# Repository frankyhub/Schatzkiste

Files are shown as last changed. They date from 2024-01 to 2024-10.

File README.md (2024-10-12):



<div align="center">

|[:skull:ISSUE](https://github.com/frankyhub/Schatzkiste/issues?q=is%3Aissue)|[:speech_balloon: Forum /Discussion](https://github.com/frankyhub/Schatzkiste/discussions)|[:grey_question:WiKi](https://github.com/frankyhub/Schatzkiste/wiki)||
|--|--|--|--|
| | | | |
||<a href="https://github.com/frankyhub/Schatzkiste/issues">|<a href="https://github.com/frankyhub/Schatzkiste/discussions">|<a href="https://github.com/frankyhub/Schatzkiste/releases">|
|| <a href="https://github.com/frankyhub/Schatzkiste/pulse" alt="Activity">| <a href="https://github.com/frankyhub/Schatzkiste/graphs/traffic">  |<a href="https://github.com/frankyhub?tab=stars"> |
</div>

# Schatzkiste

## Story

Mit diesem Projekt wird eine Schatzkiste gebaut, die sich mit dem Betätigen von vier Tasten in der 
richtigen Reihenfolge öffnen lässt. Wird eine Taste betätigt, leuchtet die darüber liegende LED. 
Ist der Tasten-Code richtig eingegeben, gehen die vier weißen LEDs über den Tasten aus, eine grüne 
LED leuchtet und die beiden Servo-Motoren öffnen den Verschluss. Ist die Schatzkiste geöffnet, kann mit jeder 
beliebigen Taste die Schatzkiste wieder verschlossen werden. Ist der Code falsch eingegeben, erlöschen 
die vier LEDS und die Schatzkiste bleibt verschlossen.
Im inneren der Schatzkiste ist ein Reed-Kontakt versteckt. Nur der Eigentümer der Schatzkiste weiß, 
wo sich der Reed-Kontakt befindet. Wird an diesen Reed-Kontakt ein Magnet gehalten, blinken die vier 
Taster-LEDs und der Code kann neu programmiert werden. Nach erfolgreicher Programmierung blinken die 
vier Taster-LEDs erneut. Der Code wird in das EEPROM des NANO geladen, so dass auch bei Spannungsausfall 
der Code erhalten bleibt.

Die Schatzkiste

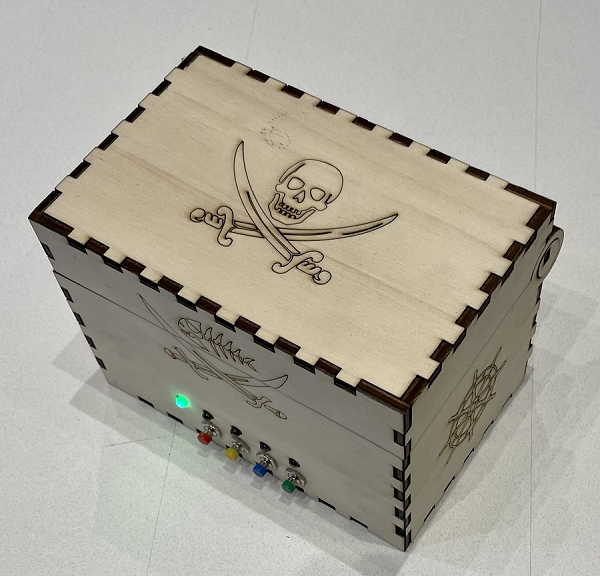
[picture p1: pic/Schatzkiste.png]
Schatzkiste


---

## Hardware
Die Stückliste für die Schatzkiste:

+ 1 x NANO
+ 1 x NANO-Shield
+ 2 x Buchsenleisten
+ 2 x Stiftleisten
+ 2 x Servo Motore SG90
+ 2 x 90° Verschluss Winkel
+ 1 x Reed-Kontakt mit Magnet
+ 4 x Taster
+ 4 x LEDs weiß
+ 1 x LED grün
+ 5 x 1kOhm Widerstand
+ 1 x 9V Batterie
+ 1 x 9V Batterie-Clip
+ 1 x Gelaserte Schatzkiste (4mm Sperrholz 600x300)

---

## Aufbau und Montage
Der Aufbau und die Montage der Schatzkiste ist in mehrere Schritte unterteilt.

## Schritt 1: Das Gehäuse
+ Erstelle auf Boxes.PY  eine "Kiste mit eingebundenen Schanier" mit den Abmessungen x=160, y=100 und h=80, Deckelhöhe 28.
+ Füge in die erstellte SVG-Grafik die Löcher für die LEDs und Taster ein
+ Füge in die erstellte SVG-Grafik deine Grafik für die Verziehrung der Schatzkiste ein
+ Schneide das Gehäuse mit dem Lasercutter aus
+ Klebe die Servo-Motoren in den Gehäusedeckel
+ Klebe die Winkel an die Frontplatte
+ Klebe den Reed-Kontakt in das Gehäuse
+ Montiere die LEDs und die Taster an die Gehäuse-Front
+ Verklebe die Gehäuseteile. Die untere Rückwand wird nicht verklebt

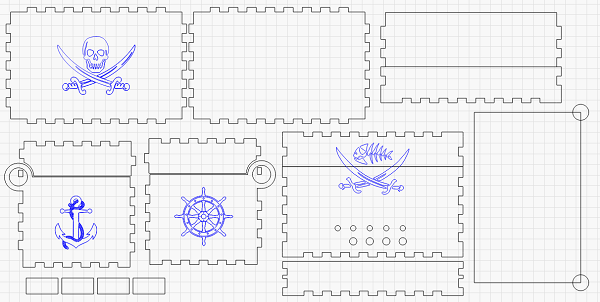
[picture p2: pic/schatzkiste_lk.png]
Schatzkiste


---

## Schritt 2: 3D-Druck
+ Zeichne und drucke 4 Platinen Füße für den NANO, D=5mm x 5mm
+ Klebe die Füße auf die Unterseite des NANO-Shields

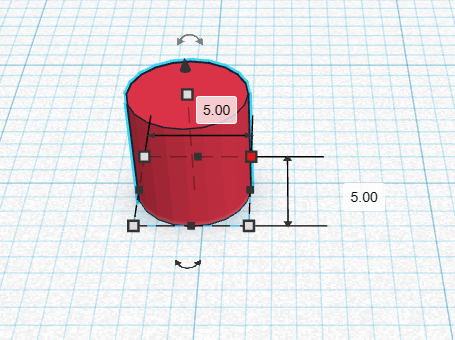
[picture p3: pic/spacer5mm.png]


---

## Schritt 3: Verdrahtung und Lötarbeiten
+ Bestücke das NANO-Shield mit den Buchsenleisten und den beiden Stiftleisten für die Servo-Motore
+ Biege an einem Ende der Widerstände und am +Pol der LEDs eine Öse

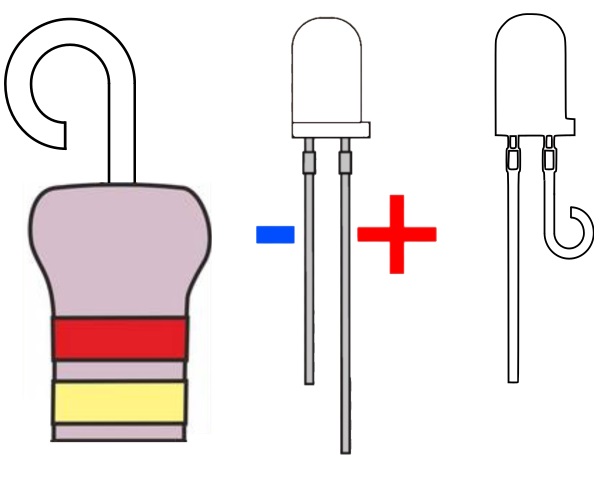
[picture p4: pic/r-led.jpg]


Führe Anschlussdrähte für die Widerstände und der LEDs durch die Öse und Löte sie an

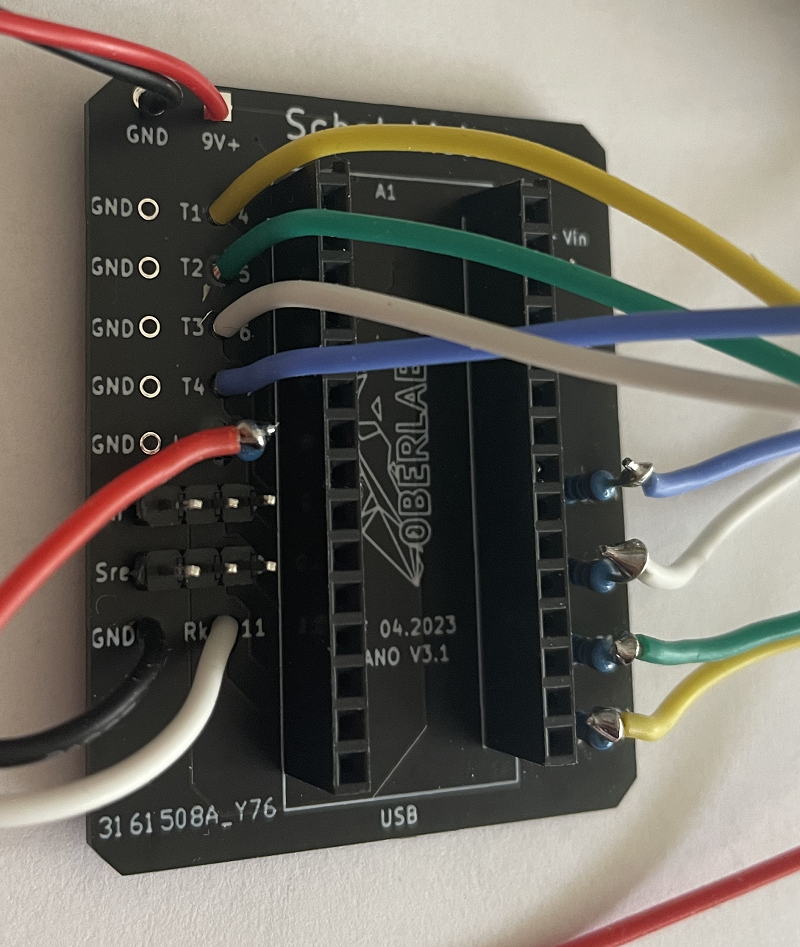
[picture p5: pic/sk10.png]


Schatzkiste

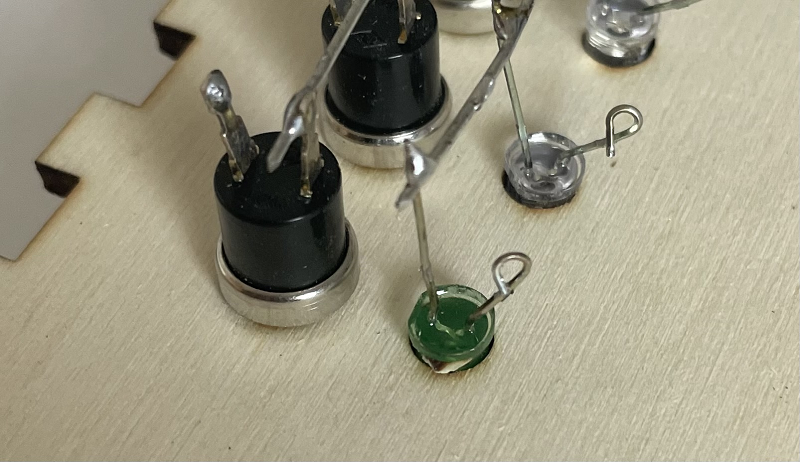
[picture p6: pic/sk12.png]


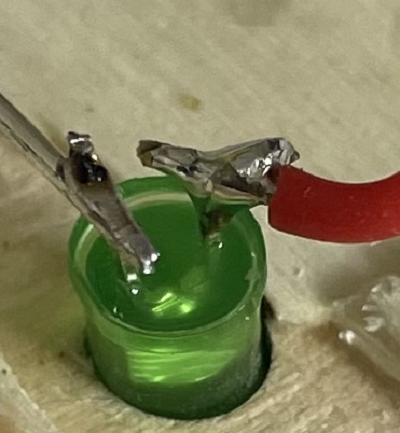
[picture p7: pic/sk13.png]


Verdrahte das Shield, die LEDs, Taster und den Reed-Kontakt nach den Verdrahtungsplan

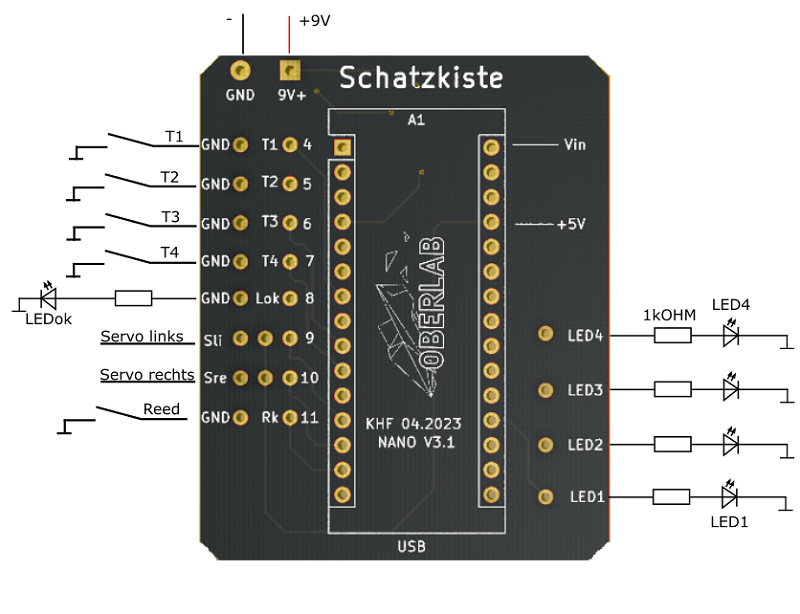
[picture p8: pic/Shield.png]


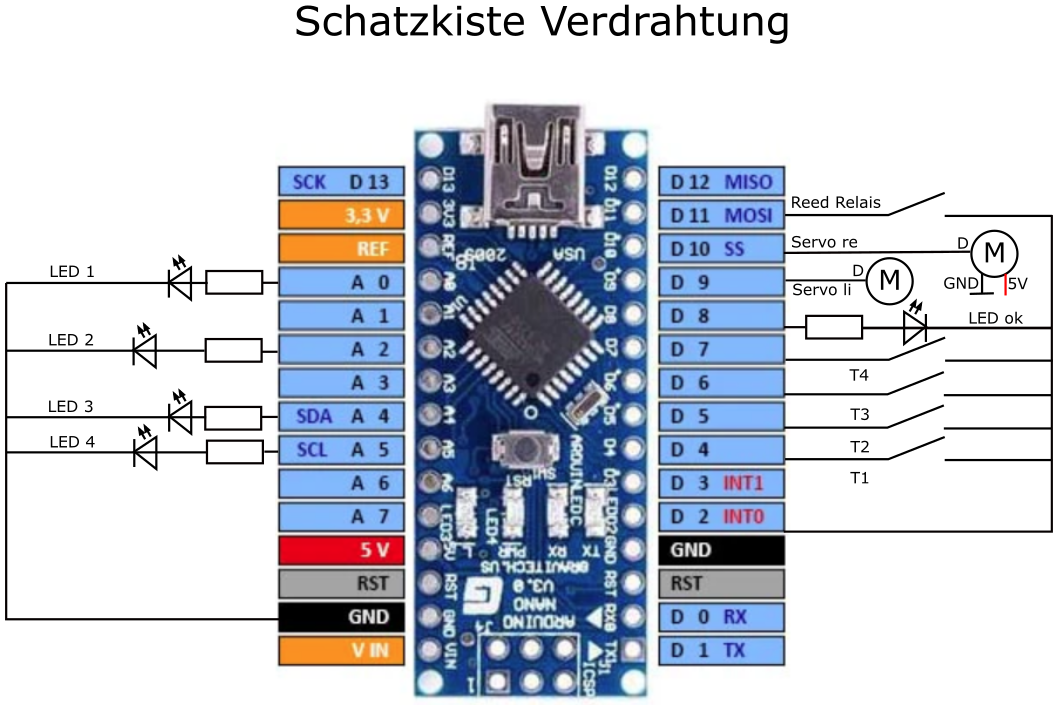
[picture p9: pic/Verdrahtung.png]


---

## Schritt 4: Inbetriebnahme
+ Kontrolliere alle Verbindungen
+ Lade das Servo-Test Programm in den NANO
+ Versorge die Schatzkiste mit Spannung
+ Teste den Verschluss-Mechanismus mit den Servo-Motoren
+ Wenn der Verschluss ok ist, lade das Haupt-Programm in den NANO
+ Das Programm befindet sich auf deinen Laptop unter Nextcloud/Schatzkiste
+ Aktiviere mit einen Magneten über den Reed-Kontakt die Programmierung des Codes
+ Gibt über die Taster deinen Code ein
+ Teste deinen Code
+ Ist der Code richtig, öffen die Servo-Motor die Verschluss-Einrichtung

---

<div style="position:absolute; left:2cm; ">   
<ol class="breadcrumb" style="border-top: 2px solid black;border-bottom:2px solid black; height: 45px; width: 900px;"> <p align="center"><a href="#oben">nach oben</a></p></ol>
</div>

---

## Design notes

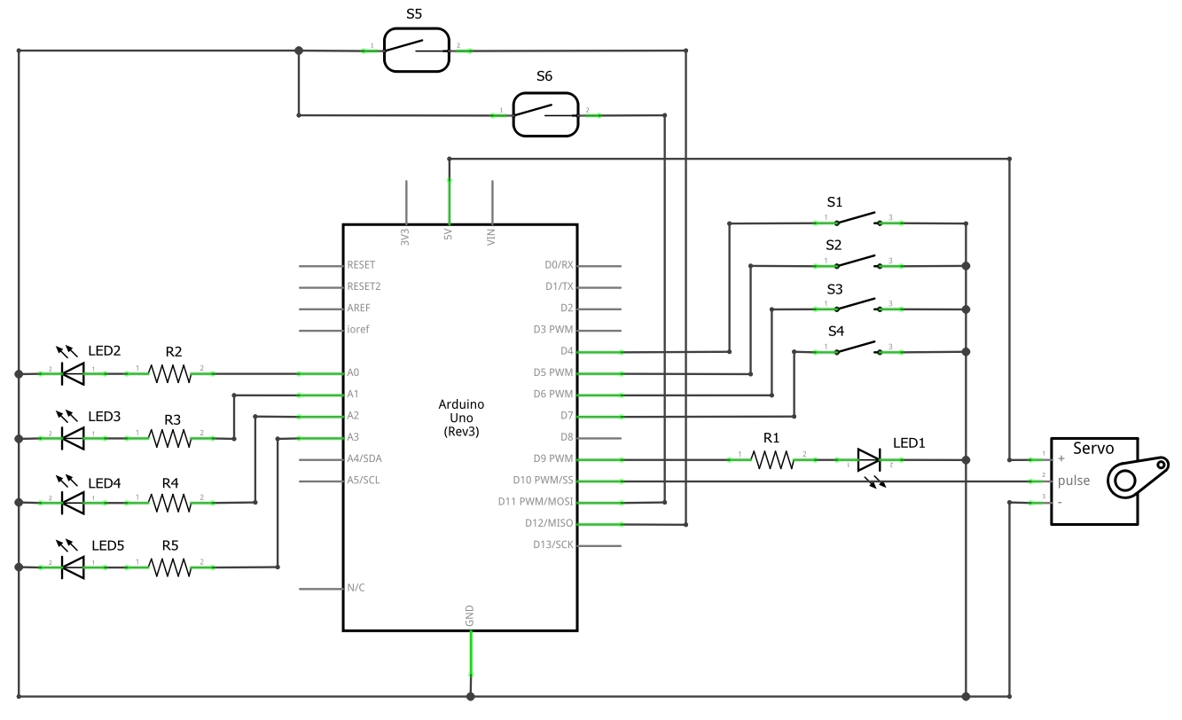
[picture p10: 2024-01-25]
pic/Schaltplan.png

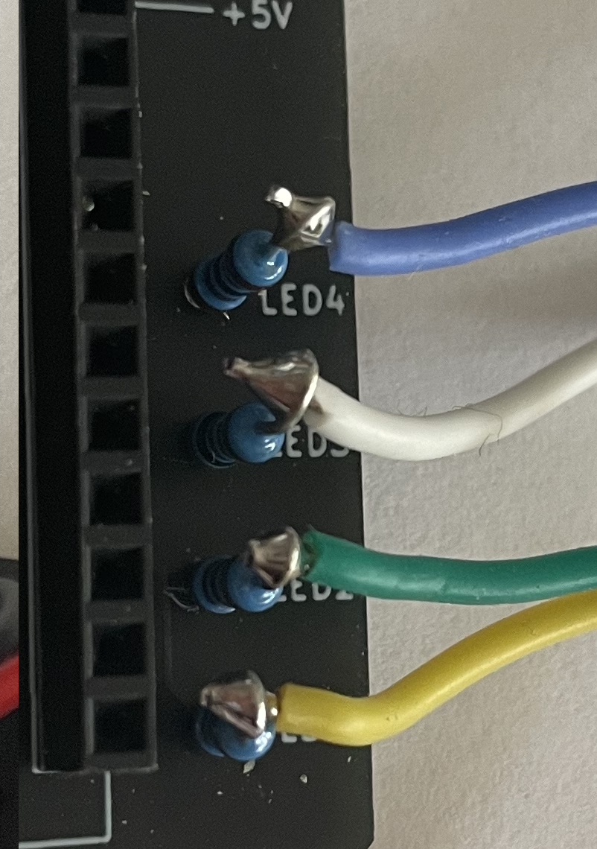
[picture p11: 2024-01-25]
pic/sk11.png

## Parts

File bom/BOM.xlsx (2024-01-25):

 | BOM Schatzkiste
10 | 1 x NANO | 60.00 € | 6.00 € | Amazon (https://www.amazon.de/dp/B078S8BJ8T/ref=twister_B07ZP9RH6Q?_encoding=UTF8&psc=1)
10 | 1 x NANO-Shield | 30.00 € | 3.00 €
10 | 1x Stift/Buchsenleiste | 10.00 € | 1.00 € | Amazon (https://www.amazon.de/gp/product/B07CC4V9ZY/ref=ppx_yo_dt_b_asin_title_o09_s00?ie=UTF8&psc=1)
20 | 2 x Servo Motor SG90 | 40.00 € | 4.00 € | Amazon (https://www.amazon.de/XTVTX-Flugzeug-Hubschrauber-Helicopter-Airplane/dp/B0BG2RDC21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)
10 | 1 x Reed-Kontakt mit Magnet | 10.00 € | 1.00 € | Amazon (https://www.amazon.de/Gebildet-Reedschalter-Magnetischer-Induktionsschalter-Mehrzweckmagneten/dp/B07Z4RR4QV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)
40 | 4 x Taster | 20.00 € | 2.00 € | Amazon (https://www.amazon.de/RUNCCI-YUN-Momentane-Druckschalter-Armaturenbrett-Montageloch%EF%BC%89/dp/B087V5VKKY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)
40 | 4 x LEDs weiß | 9.00 € | 0.90 € | Amazon (https://www.amazon.de/Lumetheus-Farbe-14-000-St%C3%BCck-Leuchtdiode/dp/B083HMLCC7)
10 | 1 x LED grün | 7.00 € | 0.70 € | Amazon (https://www.amazon.de/Lumetheus-Farbe-14-000-St%C3%BCck-Leuchtdiode/dp/B083HMLCC7)
50 | 5 x 1kOhm | 6.60 € | 0.66 € | Amazon (https://www.amazon.de/Widerstand-Verwendbar-Resistor-Suitable-A2417/dp/B07KX37J53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)
10 | 1 x 9V Batterie | 11.00 € | 1.10 € | Amazon (https://www.amazon.de/Varta-Industrial-Batterie-Alkaline-Batterien-blau/dp/B00149O6ZQ)
10 | 1 x 9V Batterie-Clip | 7.00 € | 0.70 € | Amazon (https://www.amazon.de/mmtrade-Batterieclip-9-Volt-Batterie-Anschlusskabel/dp/B09N1NQFYZ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)
20 | 2 x 90° Winkel | 6.00 € | 0.60 € | Amazon (https://www.amazon.de/gp/product/B09PFMV4L9/ref=ppx_yo_dt_b_asin_title_o00_s00?ie=UTF8&psc=1)
10 | 1 x Gelaserte Schatzkiste (4mm Sperrholz 600x300) | 40.00 € | 4.00 €
 |  | 256.60 € | 25.66 €

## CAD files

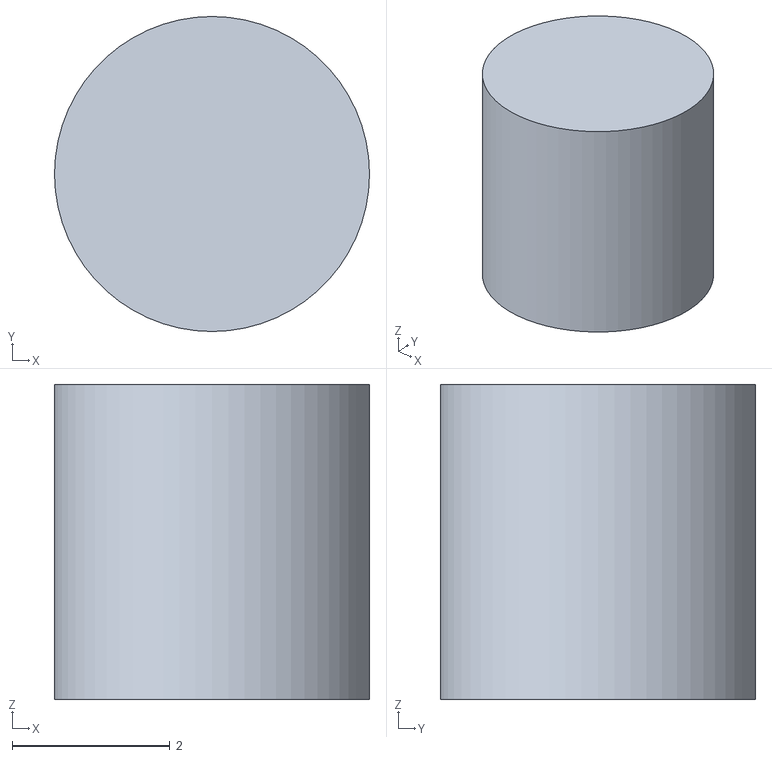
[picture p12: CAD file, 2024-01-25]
3D/Pin 4x4.stl
4.00 x 4.00 x 4.00

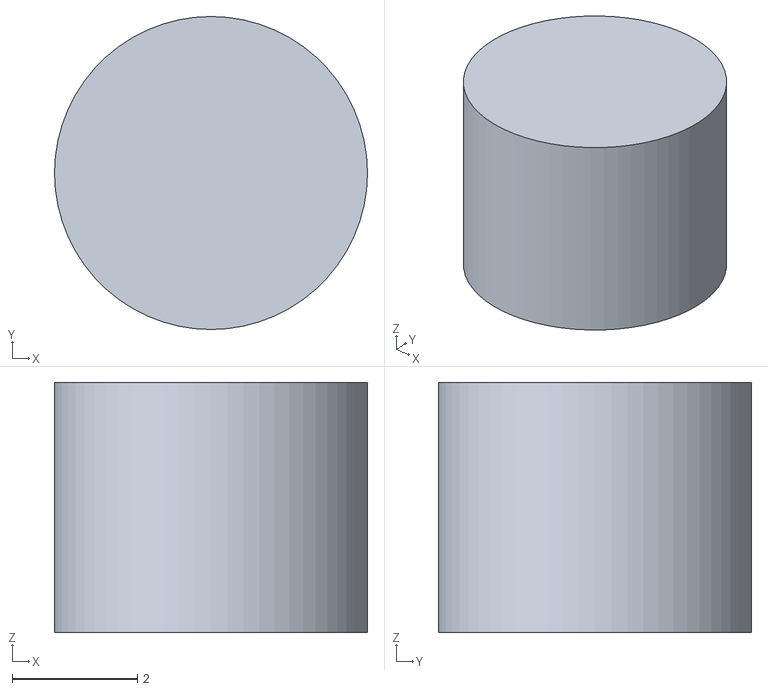
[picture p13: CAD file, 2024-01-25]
3D/Pin 4x5.stl
5.00 x 5.00 x 4.00

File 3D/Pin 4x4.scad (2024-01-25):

$fn=60;
cylinder(h=4,d=4);

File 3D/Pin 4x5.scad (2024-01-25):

$fn=60;
cylinder(h=4,d=5);

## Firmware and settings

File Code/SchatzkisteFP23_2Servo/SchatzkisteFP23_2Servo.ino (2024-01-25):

/************************************************************************************************* 
                                      PROGRAMMINFO
************************************************************************************************** 
Funktion: Schatzkiste

Mit diesem Projekt wird eine Schatzkiste gebaut, die sich mit dem Betätigen von vier Tasten in der 
richtigen Reihenfolge öffnen lässt. Wird eine Taste betätigt, leuchtet die darüber liegende LED. 
Ist der Tasten-Code richtig eingegeben, gehen die vier weißen LEDs über den Tasten aus, eine grüne 
LED leuchtet und der Servo-Motor öffnet den Verschluss. Ist die Schatzkiste geöffnet, kann mit jeder 
beliebigen Taste die Schatzkiste wieder verschlossen werden. Ist der Code falsch eingegeben, erlöschen 
die vier LEDS und die Schatzkiste bleibt verschlossen.
Im inneren der Schatzkiste ist ein Reed-Kontakt versteckt. Nur der Eigentümer der Schatzkiste weiß, 
wo sich der Reed-Kontakt befindet. Wird an diesen Reed-Kontakt ein Magnet gehalten, blinken die vier 
Taster-LEDs und der Code kann neu programmiert werden. Nach erfolgreicher Programmierung blinken die 
vier Taster-LEDs erneut. Der Code wird in das EEPROM des NANO geladen, so dass auch bei Spannungsausfall 
der Code erhalten bleibt.
**************************************************************************************************
*Die Hardware für die Schatzkiste
1 x NANO
2 x Servo Motor SG90
1 x Reed-Kontakt mit Magnet
4 x Taster
4 x LEDs weiß
1 x LED grün
1 x 9V Batterie
1 x 9V Batterie-Clip
1 x Gelaserte Schatzkiste (4mm Sperrholz 600x300)
**************************************************************************************************
*Version: 30.01.2023
**************************************************************************************************
Board: NANO
**************************************************************************************************
C++ Arduino IDE V1.8.13
**************************************************************************************************
Einstellungen:
https://dl.espressif.com/dl/package_esp32_index.json
http://dan.drown.org/stm32duino/package_STM32duino_index.json
https://raw.githubusercontent.com/espressif/arduino-esp32/gh-pages/package_esp32_dev_index.json
**************************************************************************************************
Librarys
- Servo.h  V 1.1.6
- EEPROM.h V 1.1.0
**************************************************************************************************
 */
#define PIN_LED_1         A0  //LED 1 
#define PIN_LED_2         A2  //LED 2  
#define PIN_LED_3         A4  //LED 3
#define PIN_LED_4         A5  //LED 4
#define PIN_BUTTON_1      4   //S1
#define PIN_BUTTON_2      5   //S2
#define PIN_BUTTON_3      6   //S3
#define PIN_BUTTON_4      7   //S4
#define PIN_LED_SUCCESS   8   //LED Code OK
#define PIN_SERVO1        9   //Servo1 rechts
#define PIN_SERVO2        10  //Servo2 links
#define PIN_REED_1        11  //S5 Reed-Relais


#include <Servo.h>  
#include <EEPROM.h> 

bool isDoorOpen, openDoor, buttonPressed[4];
byte buttons[4] = {PIN_BUTTON_1, PIN_BUTTON_2, PIN_BUTTON_3, PIN_BUTTON_4};
byte leds[4] = {PIN_LED_1, PIN_LED_2, PIN_LED_3, PIN_LED_4}, doorCode[4];
Servo servoMotor1;
Servo servoMotor2;

void setup()
{
  Serial.begin(115200);
  Serial.print("Init...");
  pinMode(PIN_REED_1, INPUT_PULLUP);
//  pinMode(PIN_REED_2, INPUT_PULLUP);

  pinMode(PIN_LED_SUCCESS, OUTPUT);
  digitalWrite(PIN_LED_SUCCESS, LOW);

  for (byte i = 0; i < sizeof(leds); i++) {
    pinMode(leds[i], OUTPUT);
    pinMode(buttons[i], INPUT_PULLUP);
    buttonPressed[i] = false;
  }

  blinkLEDs();
  servoMotor1.attach(PIN_SERVO1);
  servoMotor1.write(0);
  servoMotor2.attach(PIN_SERVO2);
  servoMotor2.write(90);
  
  isDoorOpen = false;

  EEPROM.get(0, doorCode);
  Serial.println("ok");

  printDoorCode();
}

void loop()
{
  checkCode();
    if (digitalRead(PIN_REED_1) == LOW) {
// if (digitalRead(PIN_REED_1) == LOW && digitalRead(PIN_REED_2) == LOW) {
  Serial.print("Reste Code");
    resetCode();
  }
  checkDoor();
}

void checkCode()
{
  static byte foundOffset = 0, pressOffset = 0, currentState;
  openDoor = false;

  for (byte i = 0; i < sizeof(buttons); i++) {
    currentState = digitalRead(buttons[i]);
    if (!buttonPressed[i] && currentState == LOW) {
      digitalWrite(leds[i], HIGH);
      buttonPressed[i] = true;
      pressOffset++;
      if (doorCode[foundOffset] == i) {
        foundOffset++;
      }
    }
  }

  if (foundOffset >= 4) {
    openDoor = true;
    pressOffset = 0;
    foundOffset = 0;
    delay(200);
  } else {
    if (pressOffset >= 4) {
      pressOffset = 0;
      foundOffset = 0;
      for (byte i = 0; i < sizeof(buttons); i++) {
        delay(200);
        buttonPressed[i] = false;
        digitalWrite(leds[i], LOW);
      }
    }
  }
}

void checkDoor()
{
  if (!isDoorOpen) {
    if (openDoor) {
      digitalWrite(PIN_LED_SUCCESS, HIGH);
      for (byte i = 0; i < sizeof(leds); i++) {
        digitalWrite(leds[i], LOW);
      }
      delay(500);
      servoMotor1.write(90);
      servoMotor2.write(0);
      isDoorOpen = true;

      delay(1000);
      while (openDoor == true) {
        for (byte i = 0; i < sizeof(buttons); i++) {
          if (digitalRead(buttons[i]) == LOW) {
            openDoor = false;
            break;
          }
        }
      }
    }
  } else {
    if (!openDoor) {
      digitalWrite(PIN_LED_SUCCESS, LOW);
      for (byte i = 0; i < sizeof(leds); i++) {
        buttonPressed[i] = false;
        digitalWrite(leds[i], LOW);
      }
      servoMotor1.write(0);
      servoMotor2.write(90);
      isDoorOpen = false;
      delay(2000);
    }
  }
}

void resetCode()
{
  servoMotor1.write(90);
  servoMotor2.write(0);
  for (byte i = 0; i < sizeof(doorCode); i++) {
    doorCode[i] = 255;
  }
  blinkLEDs();
  openDoor = false;
  isDoorOpen = false;
  bool isExisting = false;
  byte offset = 0;
  do {
    for (byte i = 0; i < sizeof(buttons); i++) {
      isExisting = false;
      if (digitalRead(buttons[i]) == LOW && doorCode[offset] == 255) {
        for (byte j = 0; j < sizeof(doorCode); j++) {
          if (doorCode[j] == i) {
            isExisting = true;
          }
        }
        if (!isExisting) {
          digitalWrite(leds[i], HIGH);
          doorCode[offset] = i;
          offset++;
        }
      }
    }
  } while (offset < 4);

  printDoorCode();
  EEPROM.put(0, doorCode); // writing code to EEPROM
  servoMotor1.write(0);
  servoMotor2.write(90);
  blinkLEDs();
}

void blinkLEDs()
{
  for (byte j = 0; j < 9; j++) {
    for (byte i = 0; i < sizeof(leds); i++) {
      digitalWrite(leds[i], j % 2);
      delay(40);
    }
  }
}

void printDoorCode()
{
  Serial.println("Code:");
  for (byte i = 0; i < sizeof(doorCode); i++) {
    Serial.print(" ");
    Serial.print(doorCode[i]);
      Serial.println();
  }
}

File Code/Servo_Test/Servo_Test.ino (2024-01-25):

/*************************************************************************************************
                                      PROGRAMMINFO
**************************************************************************************************
  Funktion: Schatzkiste Servo Test
          Die Servos müssen sich zum öffnen der Schazkiste entgegengesetzt bewegen

  Servo links D9
  Servo rechte D10
  Taster  D7 betätigt/geschlossen => GND, 

**************************************************************************************************
  Version: 28.01.2023
**************************************************************************************************
  Board: NANO 1.6.21
**************************************************************************************************
  Libraries:
  https://github.com/espressif/arduino-esp32/tree/master/libraries
  C:\Users\User\Documents\Arduino
  D:\gittemp\Arduino II\A156_Wetterdaten_V3
**************************************************************************************************
  C++ Arduino IDE V1.8.19

**************************************************************************************************
  Einstellungen:
  https://dl.espressif.com/dl/package_esp32_index.json
  http://dan.drown.org/stm32duino/package_STM32duino_index.json
  http://arduino.esp8266.com/stable/package_esp8266com_index.json
**************************************************************************************************/
#include <Servo.h>

Servo myservo_li; //Servo links
Servo myservo_re; //Servo rechts

int pos = 0;
int button = 7;  //button = LOW -> Schatzkiste zu


void setup()
{
  myservo_li.attach(9);  // Servo links
  myservo_re.attach(10);  // Servo rechts
  pinMode(pos, OUTPUT);
  pinMode(button, INPUT);

  digitalWrite (button, HIGH);
}

void loop()
{
//******* Servo links ********************
  if (digitalRead(button) == LOW)
    for (pos = 0; pos < 90; pos += 90)
    {
      myservo_li.write(pos);
    }
  if (digitalRead(button) == HIGH)
    for (pos = 90; pos >= 90; pos -= 90)
    {
      myservo_li.write(pos);
      delay(50);
    }
//******* Servo rechts ********************
  for (pos = 90; pos >= 90; pos -= 90)
  {
    myservo_re.write(pos);
  }
  if (digitalRead(button) == HIGH)
    for (pos = 0; pos < 90; pos += 90)
    {
      myservo_re.write(pos);
      delay(50);
    }
}
